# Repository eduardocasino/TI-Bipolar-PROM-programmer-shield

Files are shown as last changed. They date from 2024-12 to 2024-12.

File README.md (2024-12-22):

## TI/National Bipolar PROM Programmer

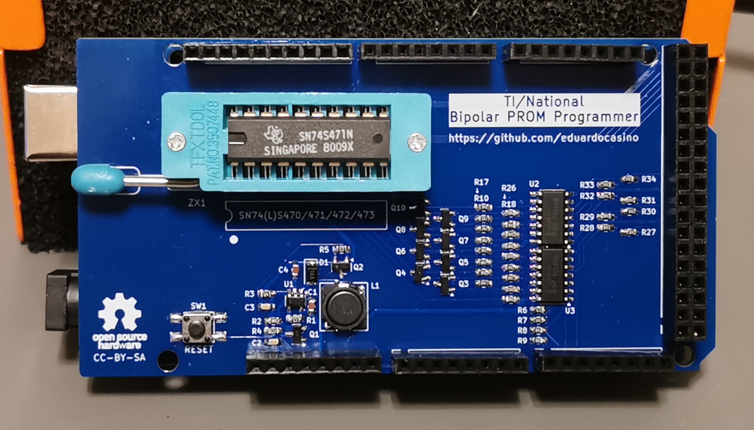
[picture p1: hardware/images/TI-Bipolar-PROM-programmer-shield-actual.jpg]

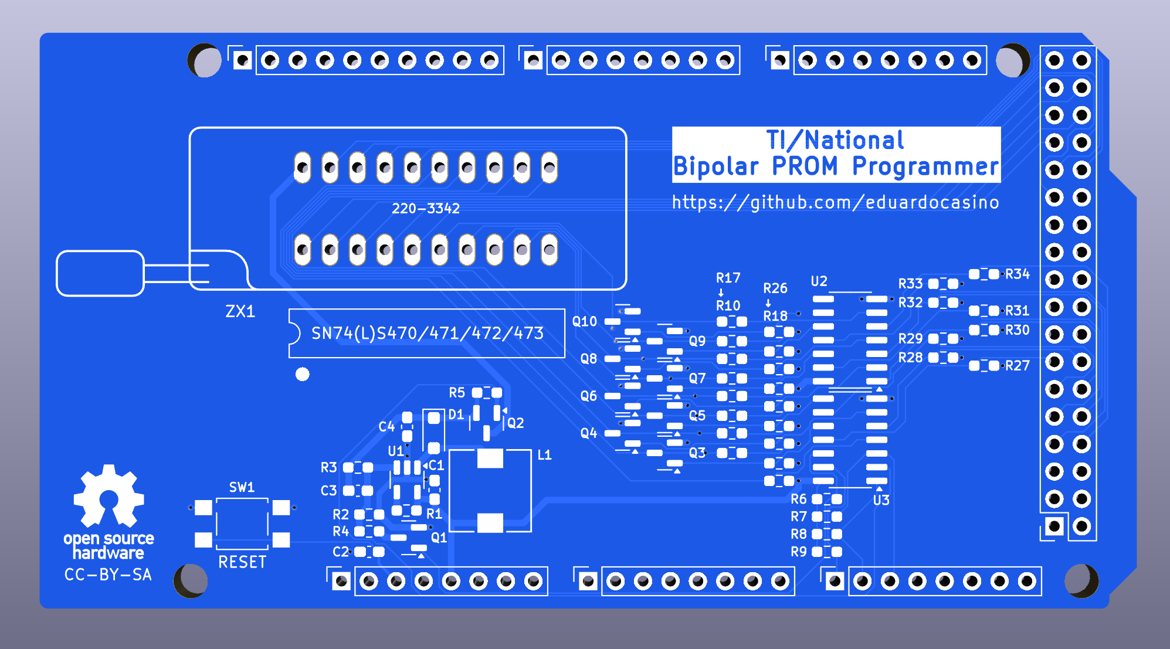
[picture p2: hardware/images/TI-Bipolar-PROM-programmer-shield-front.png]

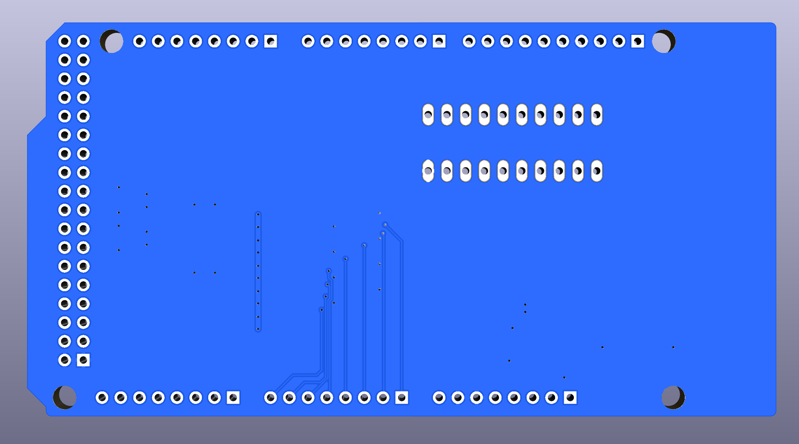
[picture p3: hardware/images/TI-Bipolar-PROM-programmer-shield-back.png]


This is a poor man's TI/National Semiconductor TTL PROM programmer shield for the Arduino Mega, based on [this design of a PROM programmer](https://theoddys.com/acorn/replica_boards/tesla_prom_programmer_board/tesla_prom_programmer_board.html) for the ACORN by Chris Oddy. It is able to program the 74s471 (256x8 bit) I've just acquired for my [K-1013 FDC Replica](https://github.com/eduardocasino/k-1013-floppy-disk-controller-replica), as well as other 256x8 and 512x8 bit PROMs from TI and Tesla.

**IMPORTANT NOTE**: Programming these chips requiere a fair amount of power, so you need to power up the Arduino with an external adapter capable of about 15W. I'm using a 12V 1A I had lying around and seems to be stable.

[This post](https://eduardocasino.es/posts/TI-National-Bipolar-PROM-Programmer/) have some additional info about the design and how it works.

### Contents

The `hardware` folder contains the KiCad project with all the necessary to generate the gerber files to fabricate your own boards.

The `firmware` folder contains the skecth you need to upload into your Arduino.

The `software` folder contains the sources of a command line utility that interfaces with the programmer. Tested only with recent Ubuntu/Debians, WSL included.

### Licensing

This is a personal project that I am sharing in case it is of interest to any retrocomputing enthusiast and all the information in this repository is provided "as is", without warranty of any kind. I am not liable for any damages that may occur, whether it be to individuals, objects, computers, kittens or any other pets. It should also be noted that everything in this repository is a work in progress, may have not been thoroughly tested and may contain errors, therefore anyone who chooses to use it does so at their own risk.

Unless otherwise noted, all the content under the `hardware` folder is licensed under a [Creative Commons Attribution-ShareAlike 4.0 International License](http://creativecommons.org/licenses/by-sa/4.0/). Check the LICENSE.md file in each directory for exceptions or third party content licensing.



The code in the `firmware` and `software` folders is under the MIT License. See the LICENSE.md files for details.

### Acknowlengements

[Chris Oddy](https://theoddys.com/acorn/replica_boards/tesla_prom_programmer_board/tesla_prom_programmer_board.html) for the original Tesla Programmer.

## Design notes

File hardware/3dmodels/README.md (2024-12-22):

* TL3305 models created by [Andrew Wyatt](https://gitlab.com/kicad/libraries/kicad-packages3D/-/merge_requests/632=)

The following 3D models are not included in this repository because of licensing restrictions:

* ZIP Socket model by [Ronald Greiner](https://www.3dcontentcentral.com/download-model.aspx?catalogid=171&id=941387)

* SRR7032 model by [Bourns](https://www.bourns.com/engineering/SRR7032/srr7032.stp)

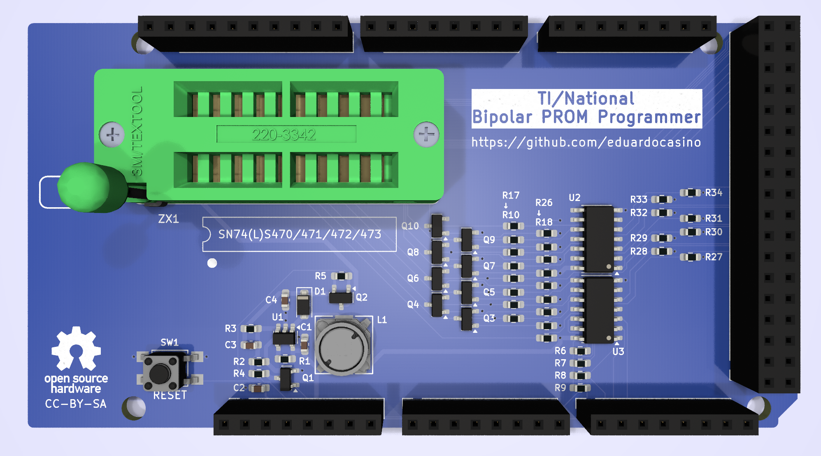
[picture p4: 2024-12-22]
hardware/images/TI-Bipolar-PROM-programmer-shield.png

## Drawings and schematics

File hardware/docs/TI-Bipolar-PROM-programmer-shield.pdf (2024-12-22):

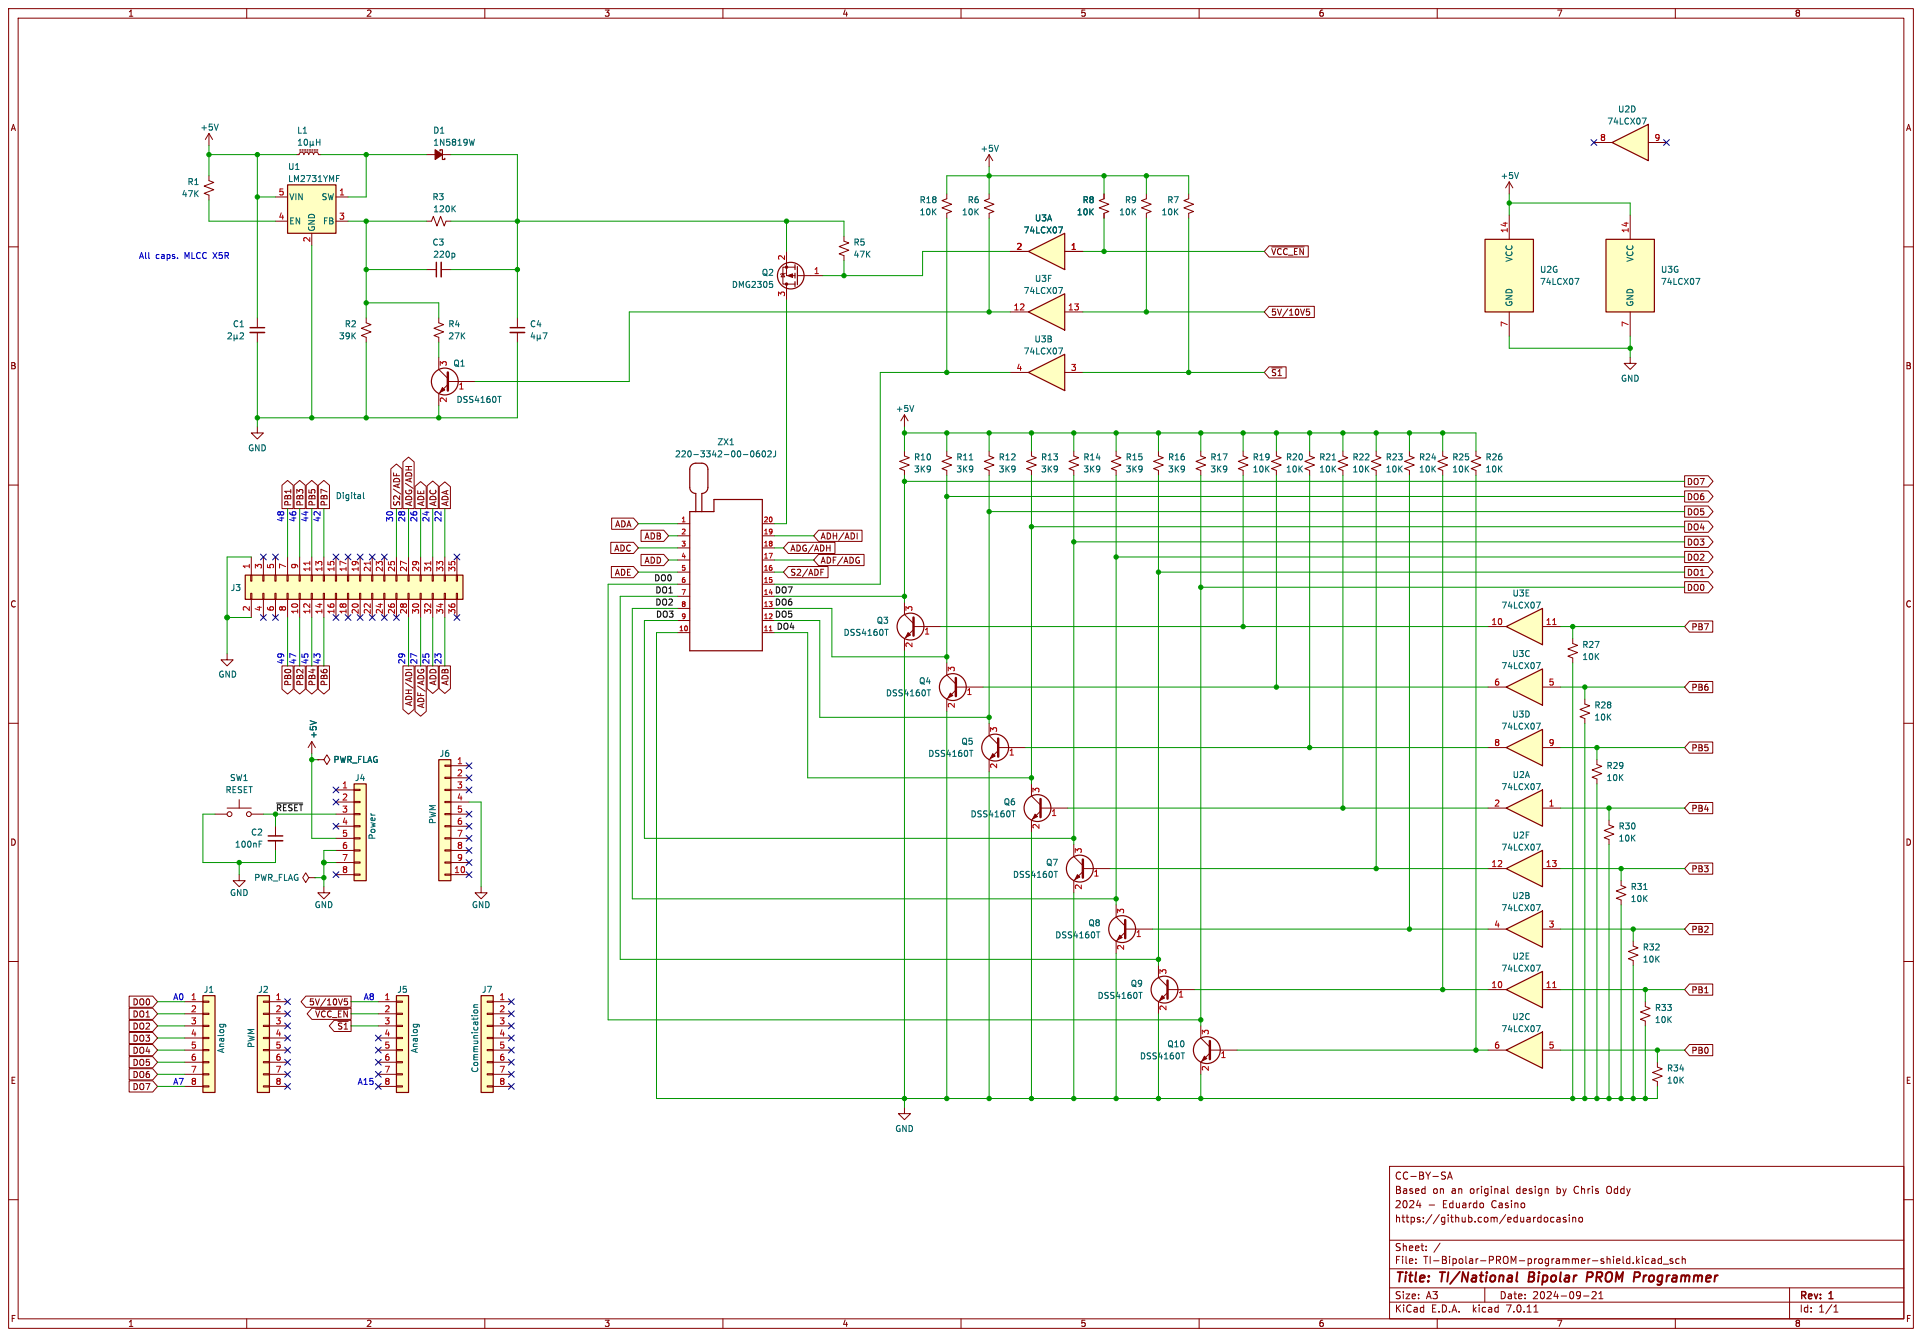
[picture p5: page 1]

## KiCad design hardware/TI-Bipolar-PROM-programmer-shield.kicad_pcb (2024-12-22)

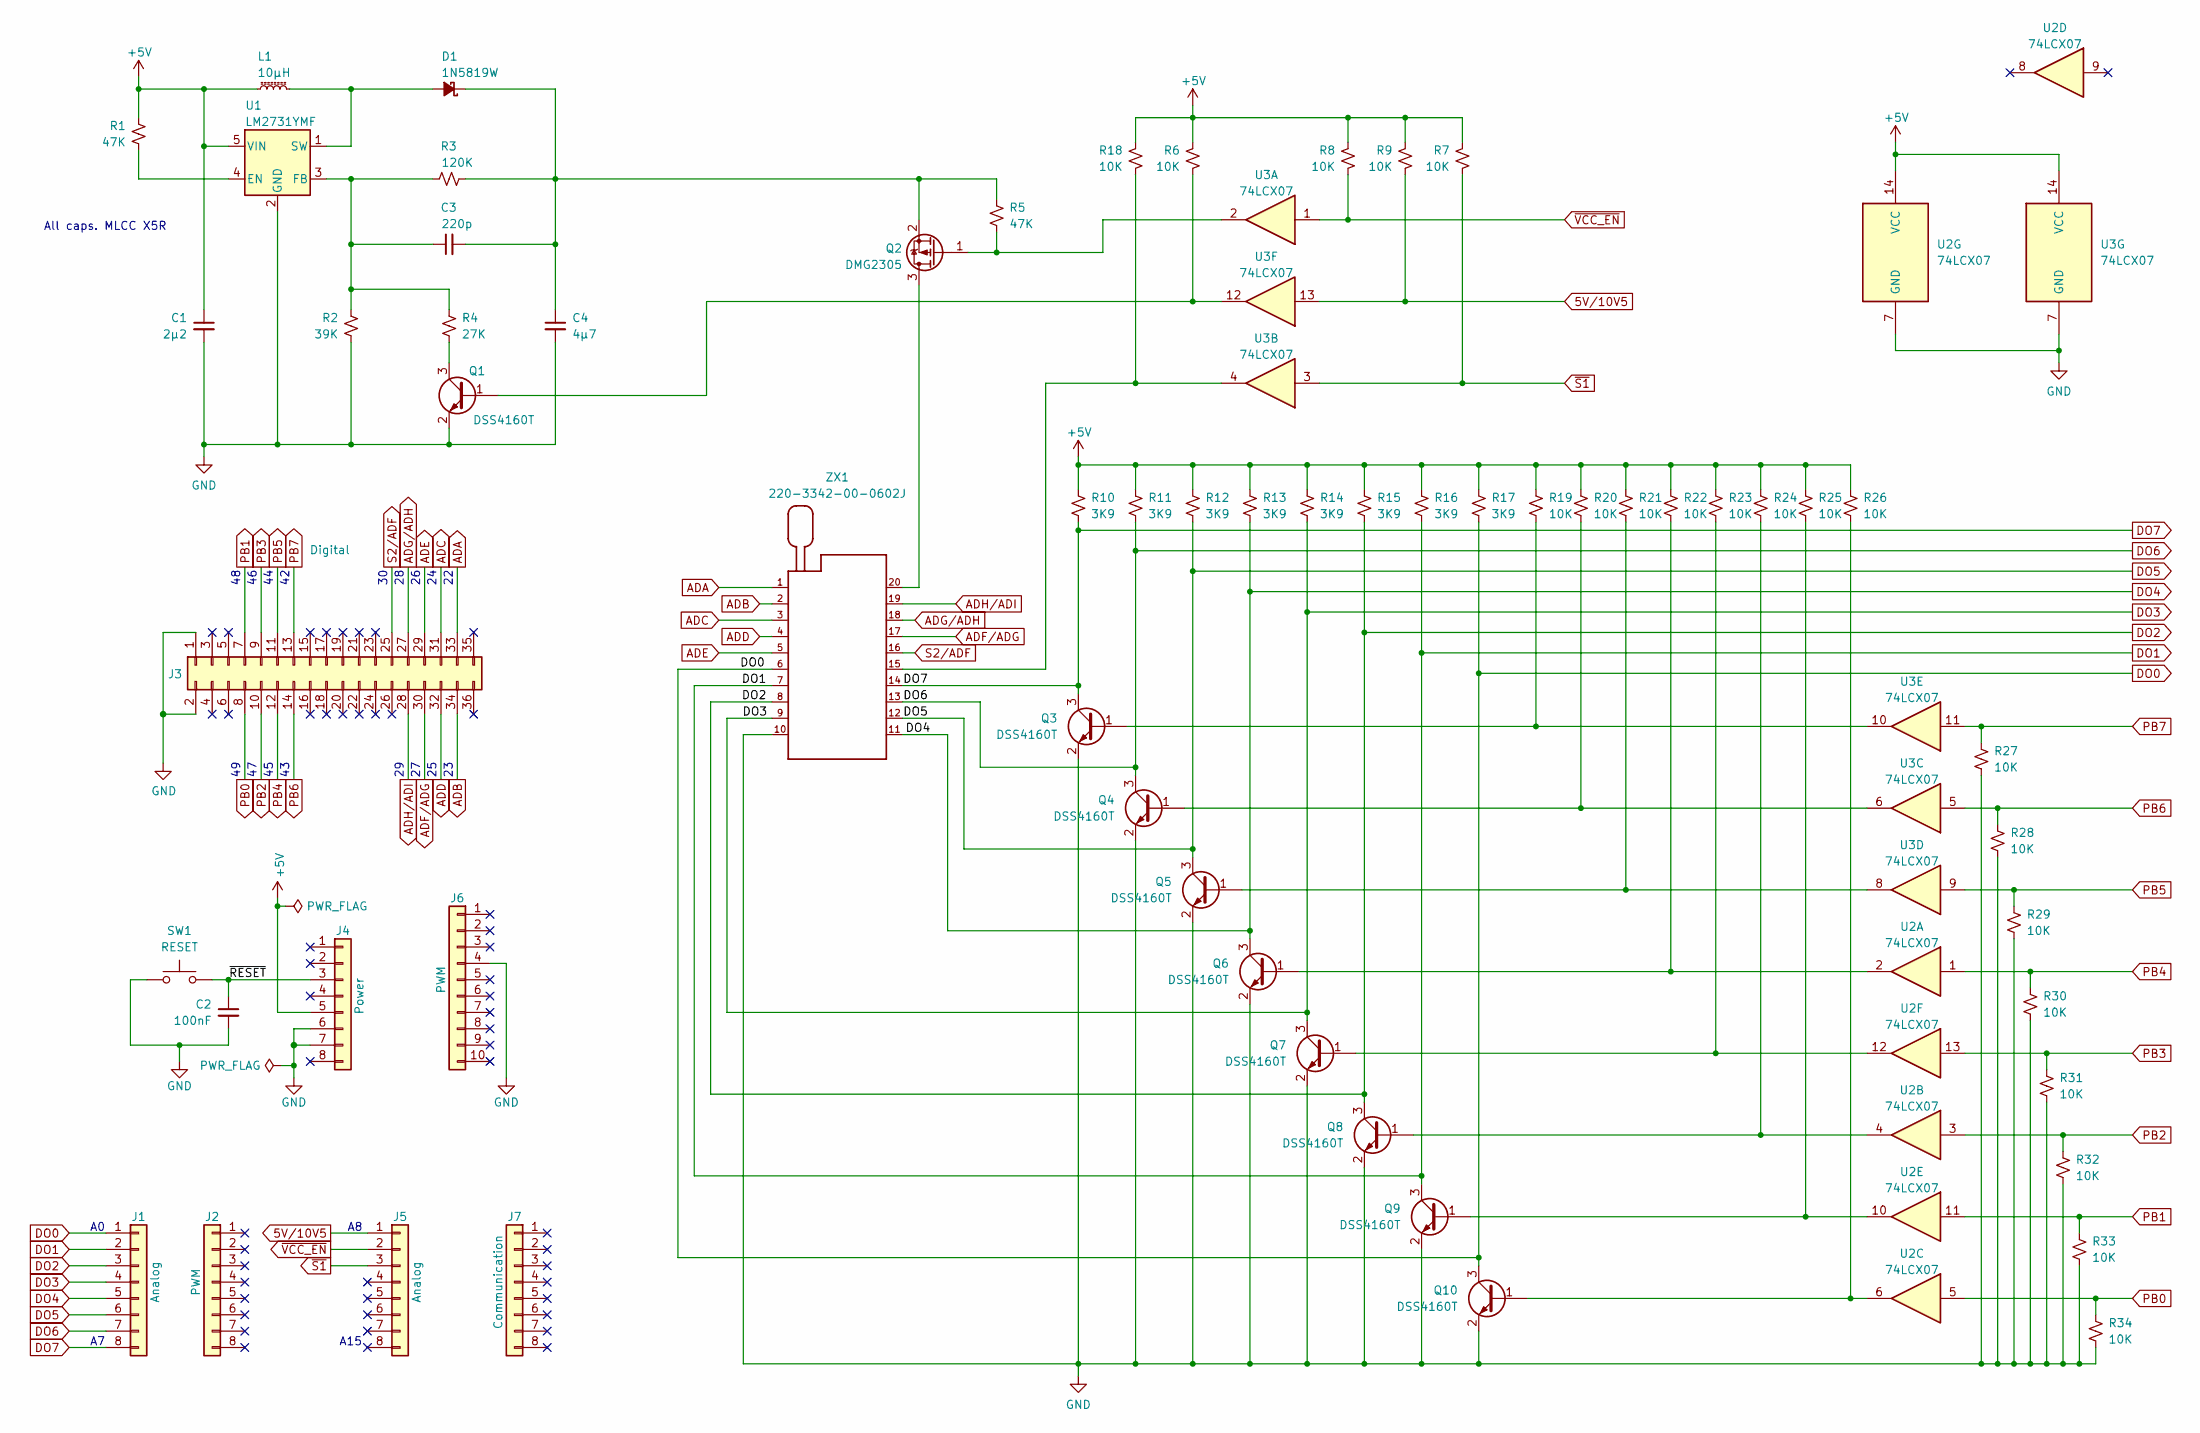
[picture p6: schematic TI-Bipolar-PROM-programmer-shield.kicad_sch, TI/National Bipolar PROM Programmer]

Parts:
C1: 2μ2; C_0603_1608Metric_Pad1.08x0.95mm_HandSolder; Digikey GRM188R61E225KA12J
C2: 100nF; C_0603_1608Metric_Pad1.08x0.95mm_HandSolder; LCSC C2762593
C3: 220p; C_0603_1608Metric_Pad1.08x0.95mm_HandSolder
C4: 4μ7; C_0603_1608Metric_Pad1.08x0.95mm_HandSolder; Digikey GRT188R61E475KE13D
D1: 1N5819W; D_SOD-123F; Digikey 1N5819W
J1, J5: Analog; PinSocket_1x08_P2.54mm_Vertical
J2: PWM; PinSocket_1x08_P2.54mm_Vertical
J3: Digital; PinSocket_2x18_P2.54mm_Vertical
J4: Power; PinSocket_1x08_P2.54mm_Vertical
J6: PWM; PinSocket_1x10_P2.54mm_Vertical
J7: Communication; PinSocket_1x08_P2.54mm_Vertical
L1: 10μH; IND_BOURNS_SRR7032; Digikey SRR7032-100M
Q1, Q3, Q4, Q5, Q6, Q7, Q8, Q9, Q10: DSS4160T; SOT-23
Q2: DMG2305; SOT-23
R1, R5: 47K; R_0603_1608Metric_Pad0.98x0.95mm_HandSolder
R2: 39K; R_0603_1608Metric_Pad0.98x0.95mm_HandSolder
R3: 120K; R_0603_1608Metric_Pad0.98x0.95mm_HandSolder
R4: 27K; R_0603_1608Metric_Pad0.98x0.95mm_HandSolder
R6, R7, R8, R9, R18, R19, R20, R21, R22, R23, R24, R25, R26, R27, R28, R29, R30, R31, R32, R33, R34: 10K; R_0603_1608Metric_Pad0.98x0.95mm_HandSolder
R10, R11, R12, R13, R14, R15, R16, R17: 3K9; R_0603_1608Metric_Pad0.98x0.95mm_HandSolder
SW1: RESET; SW_SPST_TL3305A; LCSC C2886899
U1: LM2731YMF; SOT-23-5
U2, U3: 74LCX07; SOIC-14_3.9x8.7mm_P1.27mm
ZX1: 220-3342-00-0602J; MPN 220-3342-00-0602J

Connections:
5V/10V5: J5.1, R9.2, U3.13
+5V: C1.1, J4.5, L1.1, R1.2, R6.1, R7.1, R8.1, R9.1, R10.1, R11.1, R12.1, R13.1, R14.1, R15.1, R16.1, R17.1, R18.1, R19.1, R20.1, R21.1, R22.1, R23.1, R24.1, R25.1, R26.1, U1.5 (VIN), U2.14 (VCC), U3.14 (VCC)
/~RESET: C2.1, J4.3, SW1.2
ADA: J3.33, ZX1.1
ADB: J3.34, ZX1.2
ADC: J3.31, ZX1.3
ADD: J3.32, ZX1.4
ADE: J3.29, ZX1.5
ADF/ADG: J3.30, ZX1.17
ADG/ADH: J3.27, ZX1.18
ADH/ADI: J3.28, ZX1.19
DO0: J1.1, Q10.3 (C), R17.2, ZX1.6
DO1: J1.2, Q9.3 (C), R16.2, ZX1.7
DO2: J1.3, Q8.3 (C), R15.2, ZX1.8
DO3: J1.4, Q7.3 (C), R14.2, ZX1.9
DO4: J1.5, Q6.3 (C), R13.2, ZX1.11
DO5: J1.6, Q5.3 (C), R12.2, ZX1.12
DO6: J1.7, Q4.3 (C), R11.2, ZX1.13
DO7: J1.8, Q3.3 (C), R10.2, ZX1.14
GND: C1.2, C2.2, C4.2, J3.1, J3.2, J4.6, J4.7, J6.4, Q1.2 (E), Q3.2 (E), Q4.2 (E), Q5.2 (E), Q6.2 (E), Q7.2 (E), Q8.2 (E), Q9.2 (E), Q10.2 (E), R2.2, R27.2, R28.2, R29.2, R30.2, R31.2, R32.2, R33.2, R34.2, SW1.1, U1.2 (GND), U2.7 (GND), U3.7 (GND), ZX1.10
unnamed: D1.2 (A), L1.2, U1.1 (SW)
unnamed: C3.2, C4.1, D1.1 (K), Q2.2 (S), R3.2, R5.1
unnamed: Q1.1 (B), R6.2, U3.12
unnamed: Q1.3 (C), R4.2
unnamed: Q2.3 (D), ZX1.20
unnamed: Q2.1 (G), R5.2, U3.2
unnamed: Q3.1 (B), R19.2, U3.10
unnamed: Q4.1 (B), R20.2, U3.6
unnamed: Q5.1 (B), R21.2, U3.8
unnamed: Q6.1 (B), R22.2, U2.2
unnamed: Q7.1 (B), R23.2, U2.12
unnamed: Q8.1 (B), R24.2, U2.4
unnamed: Q9.1 (B), R25.2, U2.10
unnamed: Q10.1 (B), R26.2, U2.6
unnamed: R18.2, U3.4, ZX1.15
unnamed: R1.1, U1.4 (EN)
unnamed: C3.1, R2.1, R3.1, R4.1, U1.3 (FB)
PB0: J3.8, R34.1, U2.5
PB1: J3.7, R33.1, U2.11
PB2: J3.10, R32.1, U2.3
PB3: J3.9, R31.1, U2.13
PB4: J3.12, R30.1, U2.1
PB5: J3.11, R29.1, U3.9
PB6: J3.14, R28.1, U3.5
PB7: J3.13, R27.1, U3.11
S2/ADF: J3.25, ZX1.16
~S1: J5.3, R7.2, U3.3
~VCC_EN: J5.2, R8.2, U3.1

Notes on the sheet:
All caps. MLCC X5R
A15

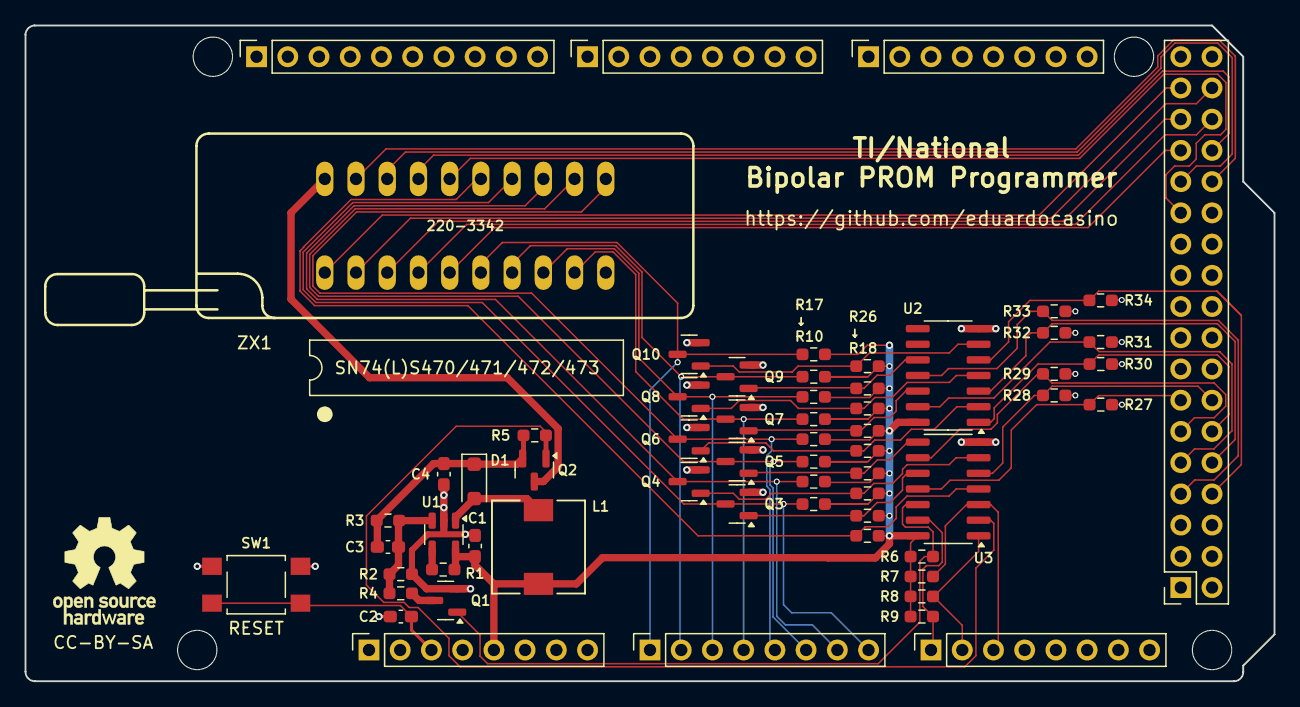
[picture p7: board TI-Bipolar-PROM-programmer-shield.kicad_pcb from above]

Board: 2 copper layers, 101.6 x 53.3 mm, 66 parts (0 on the bottom side), 48 nets.

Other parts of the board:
MH1, MH2, MH5, MH6: MountingHole_3.2mm

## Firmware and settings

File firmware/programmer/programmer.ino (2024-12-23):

// Firmware for the National/TI Bipolar PROM programmer shield
//
// (C) 2024 Eduardo Casino
//
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
// Commands:  Get version          "V"
//            Read whole PROM:     "R <CHIPNO>\n"
//            Read byte:           "r <CHIPNO> <ADDR>\n"
//            Write byte:          "w <CHIPNO> <ADDR> <BYTE>\n"
//            Simulate write byte: "s <CHIPNO> <ADDR> <BYTE>\n"
//            Blank check:         "K <CHIPNO>\n"
//            Excute test          "t <CHIPNO> <TEST_NUM> <TEST_PARAM>\n"
//                 0    Power test. Params:
//                          0  Power off
//                          1  Power on
//                          2  Set 10.5V
//                          3  Set 5V
//                 1    Chip enable. Params:
//                          0  Disable
//                          1  Enable
//                 2    Set address. Parameter is address number in hex
//                 3    Set program bit to ground. Parameter is bit mask
//
// Where:     <CHIPNO> is 0 for 740/741 and 1 for 742/743
//            <ADDR> is a three digit hex number in ascii
//            <BYTE> is a two digit hex number in ascii
//
// (V)ersion returns the version string, followed by "\r\nR\r\n"
// (R)ead prom returns the number of bytes read in hex, followed by "\r\n", followed
//        by data as an string of 2-byte hex digits, followed by "\r\nR\r\n"
// (r)ead returns the hex value, followed by "\r\nR\r\n"
// (w)rite returns the read hex value after programming, followed by "\r\nR\r\n"
// (s)imulate write returns the hex value that would have resulted after programming,
//        followed by "\r\nR\r\n"
// Blan(K) test returns the last blank address read in hex (or the memory size if all
//        blank), followed by "\r\nR\r\n"
//

// Address bus on port A:
// ADA - PA0 - Pin 22
// ADB - PA1 - Pin 23
// ADC - PA2 - Pin 24
// ADD - PA3 - Pin 25
// ADE - PA4 - Pin 26
// ADF_ADG - PA5 - Pin 27
// ADG_ADH - PA6 - Pin 28
// ADH_ADI - PA7 - Pin 29

// S2 / Extended address bus for 74s472/473 on port C (PC7)
// S2_ADF - PC7 - Pin 30

// Programming data bus on port L
// PB0 - PL0 - Pin 49
// PB1 - PL1 - Pin 48
// PB2 - PL2 - Pin 47
// PB3 - PL3 - Pin 46
// PB4 - PL4 - Pin 45
// PB5 - PL5 - Pin 44
// PB6 - PL6 - Pin 43
// PB7 - PL7 - Pin 42
  
// Reading data bus on port F
// DO0 - PF0 - Pin A0
// DO1 - PF1 - Pin A1
// DO2 - PF2 - Pin A2
// DO3 - PF3 - Pin A3
// DO4 - PF4 - Pin A4
// DO5 - PF5 - Pin A5
// DO6 - PF6 - Pin A6
// DO7 - PF7 - Pin A7

// Control signals on port K
// 5V/105V - PK0 - Pin A8
// VCC_EN  - PK1 - Pin A9
// ~S1     - PK2 - Pin A10

#define VERSION               "V010000"
#define PROG_PULSE_LENGTH      5     // In ms. Datasheet guarantees bit is programmed with a 0.9ms pulse, max 10ms
#define PROG_COOLING_DELAY    15     // In ms. Duty cycle is 25% nominal, 35% max, we go nominal

#define VCC_EN    A9
#define VCC_10V5  A8
#define S1        A10
#define S2        30

typedef enum { CHIP_256X8 = 0, CHIP_512X8, NUM_CHIPS } chip_type_t;
typedef enum { ST_ANY = 0, ST_READY, ST_WAIT_CHIP, ST_WAIT_ADDR, ST_WAIT_VALUE, ST_WAIT_TESTNO, ST_WAIT_TEST_PARAMS, ST_EXEC } state_t;

typedef struct {
  byte command;
  chip_type_t chip;               // Chip to program
  word address;                   // Address to read from / write to. Doubles as test parameters for the test command
  word value;                     // Value to write / verify. Doubles as read count for read command and test number for the test command
} cmd_data_t;

typedef state_t (*state_fn_t)( cmd_data_t *cmd_data, state_t state, state_t next );

typedef struct {
  char command;
  state_t state;
  state_fn_t function;
  state_t next_state;
} st_machine_t;

state_t print_version( cmd_data_t *cmd_data, state_t unused1, state_t unused2 );

state_t get_command( cmd_data_t *cmd_data, state_t unused, state_t next );
state_t get_chip( cmd_data_t *cmd_data, state_t unused, state_t next );
state_t get_address( cmd_data_t *cmd_data, state_t unused, state_t next );
state_t get_value( cmd_data_t *cmd_data, state_t unused, state_t next );

state_t exec_read_prom( cmd_data_t *cmd_data, state_t unused1, state_t unused2 );
state_t exec_blank_check( cmd_data_t *cmd_data, state_t unused1, state_t unused2 );
state_t exec_write_prom_byte( cmd_data_t *cmd_data, state_t unused1, state_t unused2 );
state_t exec_simul_write_prom_byte( cmd_data_t *cmd_data, state_t unused1, state_t unused2 );
state_t exec_test( cmd_data_t *cmd_data, state_t unused1, state_t unused2 );

// State machine table
const st_machine_t machine[] = {

  { '*', ST_READY, get_command, ST_WAIT_CHIP },
  { 'V', ST_ANY, print_version, ST_READY },
  { 'K', ST_WAIT_CHIP, get_chip, ST_EXEC },
  { 'K', ST_EXEC, exec_blank_check, ST_READY },
  { 'r', ST_WAIT_CHIP, get_chip, ST_WAIT_ADDR },
  { 'r', ST_WAIT_ADDR, get_address, ST_WAIT_VALUE },
  { 'r', ST_WAIT_VALUE, get_value, ST_EXEC },
  { 'r', ST_EXEC, exec_read_prom, ST_READY },
  { 'w', ST_WAIT_CHIP, get_chip, ST_WAIT_ADDR },
  { 'w', ST_WAIT_ADDR, get_address, ST_WAIT_VALUE },
  { 'w', ST_WAIT_VALUE, get_value, ST_EXEC },
  { 'w', ST_EXEC, exec_write_prom_byte, ST_READY },
  { 's', ST_WAIT_CHIP, get_chip, ST_WAIT_ADDR },
  { 's', ST_WAIT_ADDR, get_address, ST_WAIT_VALUE },
  { 's', ST_WAIT_VALUE, get_value, ST_EXEC },
  { 's', ST_EXEC, exec_simul_write_prom_byte, ST_READY },
#ifdef TEST
  { 't', ST_WAIT_CHIP, get_chip, ST_WAIT_TESTNO },
  { 't', ST_WAIT_TESTNO, get_value, ST_WAIT_TEST_PARAMS },
  { 't', ST_WAIT_TEST_PARAMS, get_address, ST_EXEC },
  { 't', ST_EXEC, exec_test, ST_READY },
#endif   
  { 0 }
};

const unsigned int chip_sizes[NUM_CHIPS] = { 256, 512 };

inline void set_address( chip_type_t chip_type, unsigned int address ) __attribute__( ( always_inline ) );
void set_address( chip_type_t chip_type, unsigned int address )
{
  if ( CHIP_256X8 == chip_type )
  {
    PORTA = address;
  }
  else
  {
    PORTA = ( address & B00011111 ) | ( ( address >> 1 ) & B11100000 );
    PORTC = ( PORTC   & B01111111 ) | ( ( address << 2 ) & B10000000 );
  }
}

inline void enable_10V5( void ) __attribute__( ( always_inline ) );
void enable_10V5( void )
{
  digitalWrite( VCC_10V5, HIGH );
}

inline void disable_10V5( void ) __attribute__( ( always_inline ) );
void disable_10V5( void )
{
  digitalWrite( VCC_10V5, LOW );
}

inline void _power_on( void ) __attribute__( ( always_inline ) );
void _power_on( void )
{
  // Power on chip
  digitalWrite( VCC_EN, LOW );
} 

inline void power_on( void ) __attribute__( ( always_inline ) );
void power_on( void )
{
  // Ensure VCC is set to 5V
  disable_10V5();

  _power_on();
}

inline void power_off( void ) __attribute__( ( always_inline ) );
void power_off( void )
{
  digitalWrite( VCC_EN, HIGH );
}

inline void output_enable( chip_type_t chip_type ) __attribute__( ( always_inline ) );
void output_enable( chip_type_t chip_type )
{
  if ( CHIP_256X8 == chip_type )
  {
    digitalWrite( S2, LOW );
  }
  digitalWrite( S1, LOW );
}

inline void output_disable( chip_type_t chip_type ) __attribute__( ( always_inline ) );
void output_disable( chip_type_t chip_type )
{
  if ( CHIP_256X8 == chip_type )
  {
    digitalWrite( S2, HIGH );
  }
  digitalWrite( S1, HIGH );
}

inline void ground_pins( byte mask ) __attribute__( ( always_inline ) );
void ground_pins( byte mask )
{
  PORTL = mask;
}

inline void pullup_pins( byte mask ) __attribute__( ( always_inline ) );
void pullup_pins( byte mask )
{
  PORTL &= ~mask;
}

inline void prog_bit( chip_type_t chip_type, byte mask ) __attribute__( ( always_inline ) );
void prog_bit( chip_type_t chip_type, byte mask )
{
  // 1. Connect each output not being programmed to 5 V through 3K9 and apply the voltage
  //    specified in the table to the output to be programmed
  ground_pins( mask );
  
  // 2. Step Vcc to 10.5 V nominal
  enable_10V5();

  // 3. Apply a low-logic-level voltage to the chip-select input(s). This should occur between
  //    10 us and 1 ms after Vcc has reached its 10V5 level.
  delayMicroseconds( 100 );
  output_enable( chip_type );

  // 4. After the X pulse time is reached, a high logic level is applied to the chip-select
  //    inputs to disable the outputs. 
  delay( PROG_PULSE_LENGTH );
  output_disable( chip_type );

  // 5. Within 10 us to 1 ms after the chip-select input(s) reach a high logic level,
  //    Vcc should be stepped down to 5V, at which level verification can be accomplished.
  disable_10V5();
  pullup_pins( mask );
}

// Returns true if the bit is programmed
inline bool read_bit( chip_type_t chip_type, byte mask ) __attribute__( ( always_inline ) );
bool read_bit( chip_type_t chip_type, byte mask )
{
  bool value;
  output_enable( chip_type );
  asm ("nop\n\t");                    // 62.5ns delay, just in case
  value = PINF & mask;
  output_disable( chip_type );

  return value;
}

inline state_t _set_st_ready( void ) __attribute__( ( always_inline ) );
state_t _set_st_ready( void )
{
  Serial.println( "R" );

  return ST_READY;
}

inline state_t set_st_ready( void ) __attribute__( ( always_inline ) );
state_t set_st_ready( void )
{
  power_off();

  return _set_st_ready();
}

inline state_t _set_st_error( void ) __attribute__( ( always_inline ) );
state_t _set_st_error( void )
{
  Serial.println( "E" );

  return ST_READY;
}

inline state_t set_st_error( void ) __attribute__( ( always_inline ) );
state_t set_st_error( void )
{
  power_off();

  return _set_st_error();
}

void wait_first_non_blank( void )
{
  byte char_in = ' ';

  while ( isSpace( char_in ) )
  {
    while ( !Serial.available() )
      ;
    if ( isSpace( char_in = Serial.peek() ) )
    {
      Serial.read();
    }
  }
}

long int get_hex( void )
{
  byte digit;
  long int hex = 0;

  wait_first_non_blank();

  do
  {
    while ( !Serial.available() )
      ;
    digit = Serial.read();

    if ( isHexadecimalDigit( digit ) )
    {
      hex <<= 4;

      if ( digit >= '0' && digit <= '9' )
      {
        hex += digit - '0';
      }
      else if ( digit >= 'A' && digit <= 'F' )
      {
        hex += digit - 'A' + 10;
      }
      else if ( digit >= 'a' && digit <= 'f' )
      {
        hex += digit - 'a' + 10;
      }
    }
    else if ( !isSpace( digit ) )
    {
      return -1;
    }
  } while ( !isSpace( digit ) );

  return hex;
}

state_t get_value( cmd_data_t *cmd_data, state_t unused, state_t next )
{
  long int value = get_hex();

  if (value < 0 || value > chip_sizes[cmd_data->chip] )
  {
    return set_st_error();
  }

  cmd_data->value = (word) value;

  return next; 
}

state_t get_address( cmd_data_t *cmd_data, state_t unused, state_t next )
{
  long int address = get_hex();

  if ( address < 0 || address >= chip_sizes[cmd_data->chip] )
  {
    return set_st_error();
  }

  cmd_data->address = (word) address;

  return next; 
}

state_t get_command( cmd_data_t *cmd_data, state_t unused, state_t next )
{
  int c;

  wait_first_non_blank();

  cmd_data->command = Serial.read();

  for ( c = 0; machine[c].command != cmd_data->command; ++c )
    ;
    
  if ( machine[c].command == '\0' )
  {
    return set_st_error();
  }
    
  return next;
}

state_t get_chip( cmd_data_t *cmd_data, state_t unused, state_t next )
{
  wait_first_non_blank();

  char chip_c = Serial.read();

  if ( chip_c != '0' && chip_c != '1' )
  {
     return set_st_error();
  }

  cmd_data->chip = chip_c - '0';

  return next;
}

byte read_prom_byte( chip_type_t chip_type, unsigned int address )
{
  byte value;

  set_address( chip_type, address );
  output_enable( chip_type );
  asm ("nop\n\t");                    // 62.5ns delay, just in case
  value = PINF;
  output_disable( chip_type );
  return value;
}

#ifdef TEST
state_t exec_test( cmd_data_t *cmd_data, state_t unused1, state_t unused2 )
{
  unsigned long start, now;
  byte mask;

  switch ( cmd_data->value )          // Remember: 'value' doubles as test number
  {
    case 0:                           // Power tests
      switch ( cmd_data->address )    // Remember: 'address' doubles as test parameter
      {
        case 0:                       // Power off
          Serial.println( "Powering off" );
          power_off();
          break;
        
        case 1:                       // Power on
          Serial.println( "Powering on" );
          _power_on();                // Powers on without disabling 10V5 (if set)
          break;

        case 2:                       // Set 10V5
          Serial.println( "Setting 10V5" );
          enable_10V5();
          break;
        
        case 3:                       // Set 5V
          Serial.println( "Setting 5V" );
          disable_10V5();
          break;
        
        default:                      // Invalid parameter
          Serial.println( "Invalid test parameter" );
          return _set_st_error();     // Set ST_ERROR without powering off
      }
      break;
    
    case 1:                           // Chip enable/disable tests
      switch ( cmd_data->address )    // Remember: 'address' doubles as test parameter
      {
        case 0:                       // Disable chip
          Serial.println( "Disabling chip output" );
          output_disable( cmd_data->chip );
          break;
        
        case 1:                       // Enable chip
          Serial.println( "Enabling chip output" );
          output_enable( cmd_data->chip );
          break;

        default:                      // Invalid parameter
          Serial.println( "Invalid test parameter" );
          return _set_st_error();     // Set ST_ERROR without powering off
      }
      break;

    case 2:                           // Address selection test
      Serial.print( "Setting address " );
      Serial.println( cmd_data->address, HEX );
      set_address( cmd_data->chip, cmd_data->address );
      break;

    case 3:                           // Data pin grounding test
      mask = (byte) cmd_data->address; // Remember: 'address' doubles as test parameter
      Serial.print( "Grounding pins " );
      Serial.println( mask, BIN );
      ground_pins( mask );
      break;

    default:                          // Invalid test
      Serial.println( "Invalid test number" );
      return _set_st_error();         // Set ST_ERROR without powering off
  }

  return _set_st_ready();             // Set ST_READY without powering off
}
#endif

state_t write_prom_byte( cmd_data_t *cmd_data, bool do_write )
{
  byte existing, returned, mask;
  bool programmed;
  
  power_on();

  existing = read_prom_byte( cmd_data->chip, cmd_data->address );    // This also set the address bus
  returned = existing;

  if ( existing != cmd_data->value )
  {
    for ( int bit = 0; bit < 8; ++bit )
    {
      mask = 1 << bit;

      // Check every bit to see if it needs programming
      if ( (existing & mask) != (cmd_data->value & mask) )
      {
        // Bits are different
        if ( ! (existing & mask) )
        {
          // They are different, but it is not programmed. Okay, burn it
          // Address was already set by read_prom_byte()
          //
          if ( do_write )
          {
            _power_on();

            prog_bit( cmd_data->chip, mask );
            delayMicroseconds( 10 );
            // Verify that bit is programmed
            programmed = read_bit( cmd_data->chip, mask );
      
            power_off();

            delay( PROG_COOLING_DELAY );

            if ( ! programmed )
            {
              // Stop here, there was a problem programming the last bit
              break;
            }
          }

          returned |= mask;
        }
        else
        {
          // Stop there, because bits are different and already programmed
          break;
        }
      }
    }
  }
  
  // Return programmed value
  Serial.println( returned, HEX );

  return set_st_ready();
}

state_t exec_write_prom_byte( cmd_data_t *cmd_data, state_t unused1, state_t unused2 )
{
  return write_prom_byte( cmd_data, true );
}

state_t exec_simul_write_prom_byte( cmd_data_t *cmd_data, state_t unused1, state_t unused2 )
{
  return write_prom_byte( cmd_data, false );
}

state_t exec_read_prom( cmd_data_t *cmd_data, state_t unused1, state_t unused2 )
{
  unsigned int address;
  byte data;

  power_on();

  for ( address = cmd_data->address; address < cmd_data->address+cmd_data->value; ++address )
  {
    data = read_prom_byte( cmd_data->chip, address ); 
    Serial.print( data < 16 ? "0" : "");
    Serial.print( data, HEX );
  }
  Serial.println( "" );

  return set_st_ready();
}

state_t exec_blank_check( cmd_data_t *cmd_data, state_t unused1, state_t unused2 )
{
  unsigned int address;
  byte data;

  power_on();
  
  for ( address = 0; address < chip_sizes[cmd_data->chip]; ++address )
  {
    if ( 0 != ( data = read_prom_byte( cmd_data->chip, address ) ) )
    {
      break;
    }
  }
  Serial.println( address, HEX );

  return set_st_ready();
}

state_t print_version( cmd_data_t *cmd_data, state_t unused1, state_t unused2 )
{
  Serial.println( VERSION );

  return set_st_ready();
}

state_t programmer_init( cmd_data_t *cmd_data )
{
  memset( cmd_data, 0, sizeof( cmd_data_t ) );
  
  return set_st_ready();
}

void setup( void )
{

  // Set pin directions
  //
  DDRA =  0xFF;       // Set address bus to output
  DDRC |= B10000000;  // Set extended address pin / S2 to output
  DDRF =  0;          // Set reading data bus to input
  DDRL =  0xFF;       // Set programming data bus to output
  DDRK |= B00000111;  // Set control signals to output

  // Ensure pull-ups are disabled for PORTF
  PORTF = 0;
  
  power_off();
  disable_10V5();
  ground_pins( 0 );
  output_disable( CHIP_256X8 );
  output_disable( CHIP_512X8 );

  Serial.begin( 57600 );
}

void loop( void )
{
  int index;
  cmd_data_t cmd_data;
  state_t state = programmer_init( &cmd_data );

  while ( true )
  {
    if ( Serial.available() > 0 )
    {
      char next_char = Serial.peek();

      if ( isSpace( next_char ) )
      {
        // Just ignore
        Serial.read();
        continue;
      }
    }

    for ( index = 0; 0 != machine[index].command; ++index )
    {
      if ( ( machine[index].command == '*' || machine[index].command == cmd_data.command )
          && ( machine[index].state == state || machine[index].state == ST_ANY ) )
      {
        state = machine[index].function( &cmd_data, state, machine[index].next_state );
        break;
      }
    }

    if ( 0 == machine[index].command )
    {
      state = set_st_error();
    }
  }
}

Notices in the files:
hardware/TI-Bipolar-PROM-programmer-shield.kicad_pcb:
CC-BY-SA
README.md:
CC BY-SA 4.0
